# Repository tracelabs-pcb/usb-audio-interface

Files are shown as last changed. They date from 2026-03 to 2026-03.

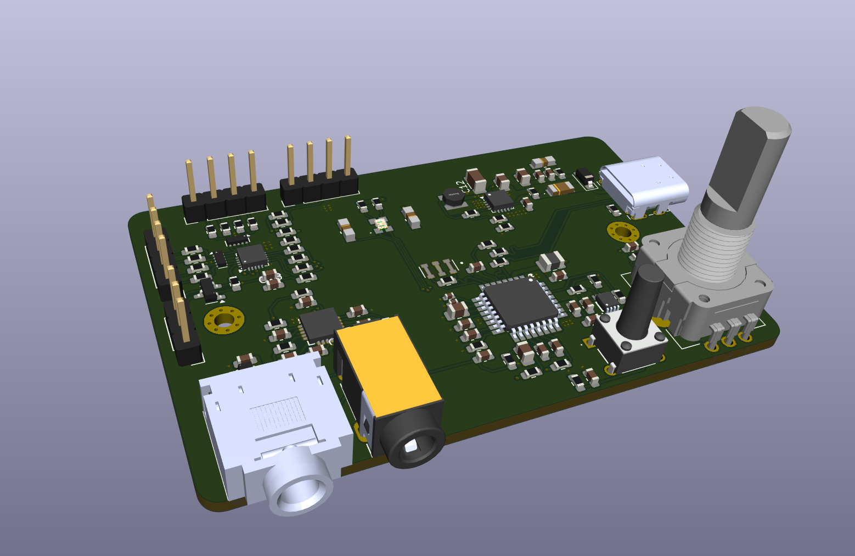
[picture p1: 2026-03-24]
screenshots/pcb_3d.png

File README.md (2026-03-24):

USB-C Audio Interface — Desktop / Streaming / Meetings

**Status: PCB-Design abgeschlossen — unbestückt**  
**Tool:** KiCad | **Layer:** 4-Layer | **Hersteller-ready:** Ja

---

## Projektbeschreibung

Kompaktes USB-C Audio-Interface für Desktop, Streaming und Meetings.
Wird am PC/Mac/Linux als Standard-USB-Audio-Device (UAC2) erkannt,
ohne Treiber. Entwickelt als reproduzierbarer Prototyp mit sauberem
Mixed-Signal-Layout (Analog + Digital).

**Besonderheiten:**
- USB Audio Class 2 (UAC2) — Plug & Play, treiberlos
- Stereo Kopfhörerverstärker mit I²C-Lautstärkeregelung (DirectPath)
- Elektret-Mikrofon-Bias + Hardware-Mute
- Rotary Encoder für Lautstärke + Mute
- Getrennte Digital/Analog-Versorgung (Buck → 3V3D → LDO → 3V3A)
- ESD-Schutz USB + Audio
- Testpunkte für alle kritischen Rails und Signale

---

## Hardware

| Komponente | Beschreibung |
|---|---|
| USB Audio Codec | PCM2912APJTR (ADC + DAC, USB-Enumeration integriert) |
| Kopfhörerverstärker | TPA6130A2RTJR (Stereo, I²C Volume, DirectPath/Capless) |
| Steuer-MCU | ATtiny1616 (Encoder, I²C, Button Handling) |
| Buck Converter | TPS62150A (5V → 3.3V Digital) |
| Analog LDO | TPS7A2033PDBVR (3.3V Digital → 3.3V Analog, Low-Noise) |
| ESD-Schutz | TPD4E05U06DQAR (USB, Audio, GPIO) |
| Stackup | 4-Layer (Signal / GND-Plane / Power / Signal+Pour) |
| Tool | KiCad |

---

## Anschlüsse

- USB-C  — Daten + Versorgung (Bus-Powered)
- TRRS 3.5mm Klinke CTIA (Headset: Mic + L/R + GND)
- Rotary Encoder (Lautstärke + Mute)
- LEDs: Power, Mic-Mute, Clip/Status
- I²C Header (OLED / Erweiterung)
- GPIO Header
- UPDI Header (ATtiny Programmierung)

---

## Architektur

**Versorgung:**
USB 5V → Buck (TPS62150A) → 3V3 Digital → LDO (TPS7A2033) → 3V3 Analog

**Signalführung:**
- USB D+/D− als Differential Pair
- Audio-Pfade kurz, getrennt von Digital
- Keine GND-Splits — gemeinsame GND-Plane (L2 durchgehend)

**Testpunkte:** 5V, 3V3D, 3V3A, GND, USB D+/D−, Audio-Nodes

---

## Ausschlüsse

Kein Serienprodukt — kein CE/EMV, keine Normenfreigabe,
keine sicherheitskritischen Funktionen.

---

## Dateien in diesem Repository

- `/kicad/` — KiCad Projektdateien
- `/screenshots/` — PCB- und Schematic-Ansichten

---

> Entwickelt von [Shawn Schneider](https://tracelabs-pcb.de)  
> — PCB-Design & Lötservice, Wolfsburg

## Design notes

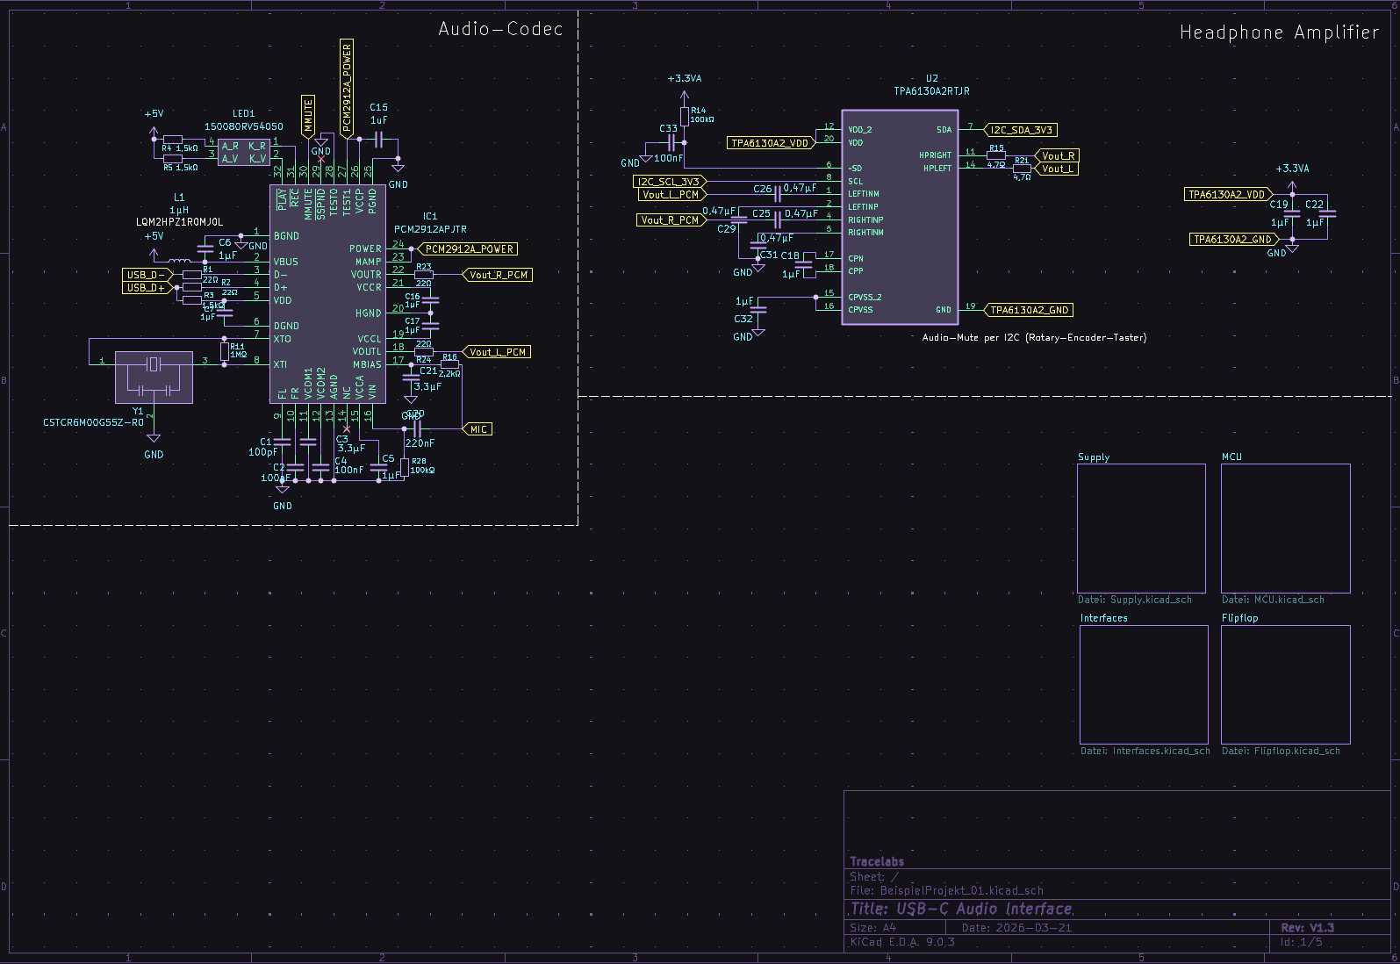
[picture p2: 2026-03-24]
screenshots/schematic_main.png

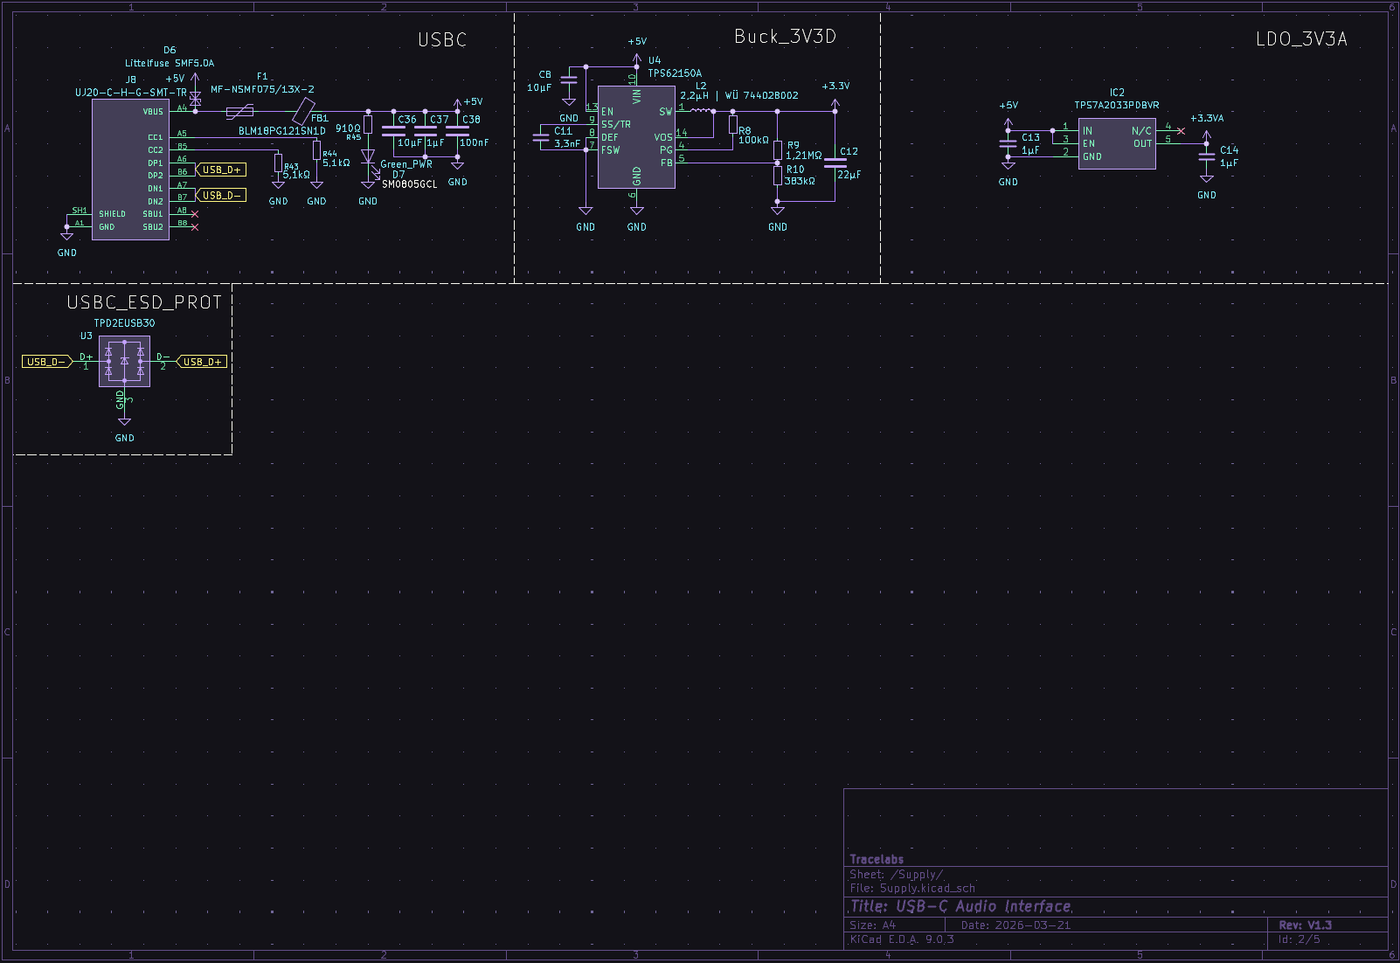
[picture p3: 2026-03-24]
screenshots/schematic_supply.png

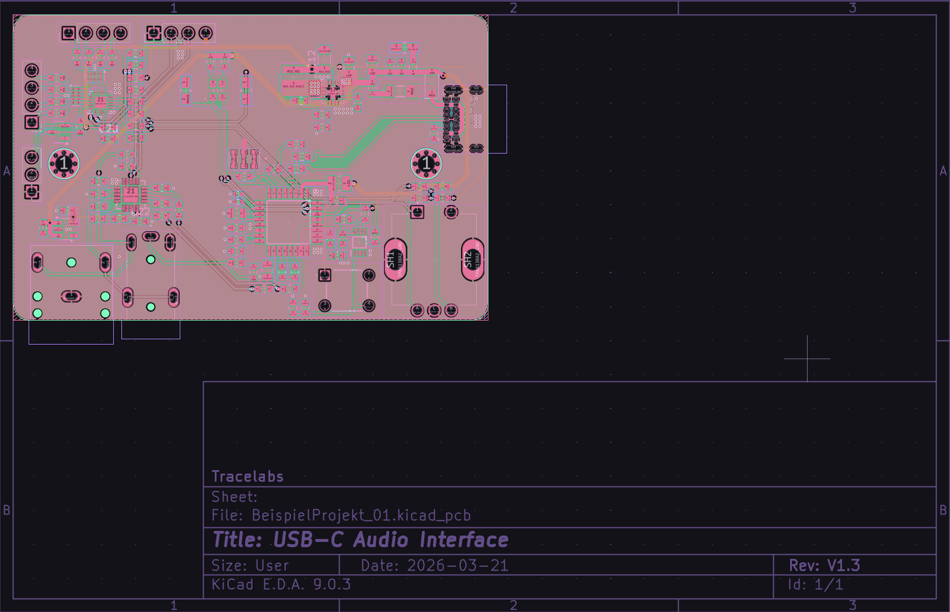
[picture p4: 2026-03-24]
screenshots/pcb_all_layers.png

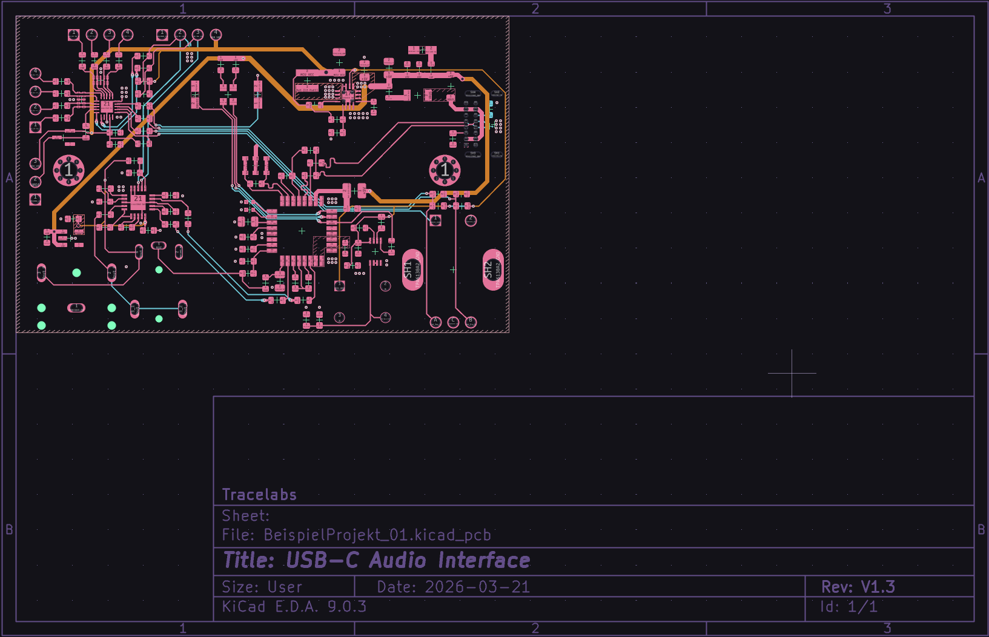
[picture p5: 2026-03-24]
screenshots/pcb_routing.png

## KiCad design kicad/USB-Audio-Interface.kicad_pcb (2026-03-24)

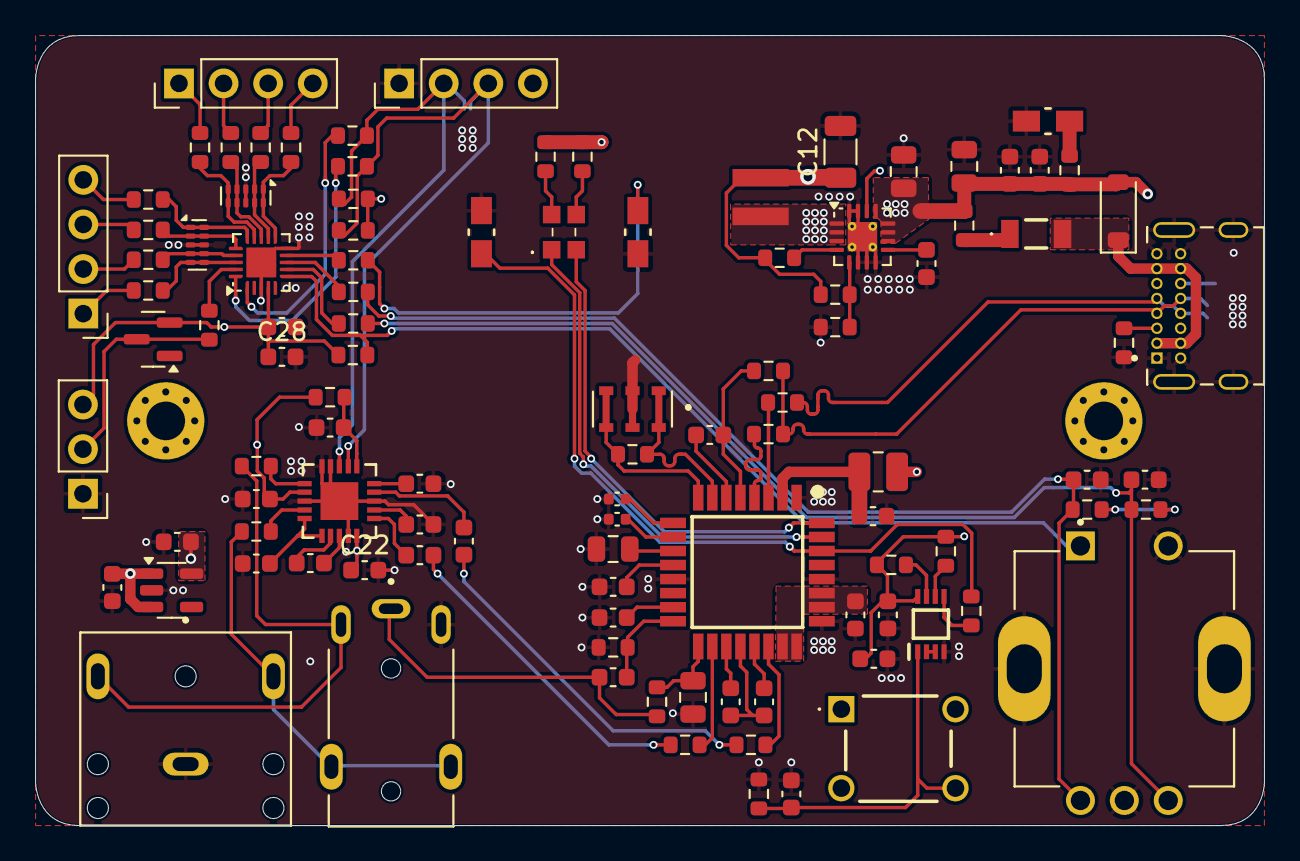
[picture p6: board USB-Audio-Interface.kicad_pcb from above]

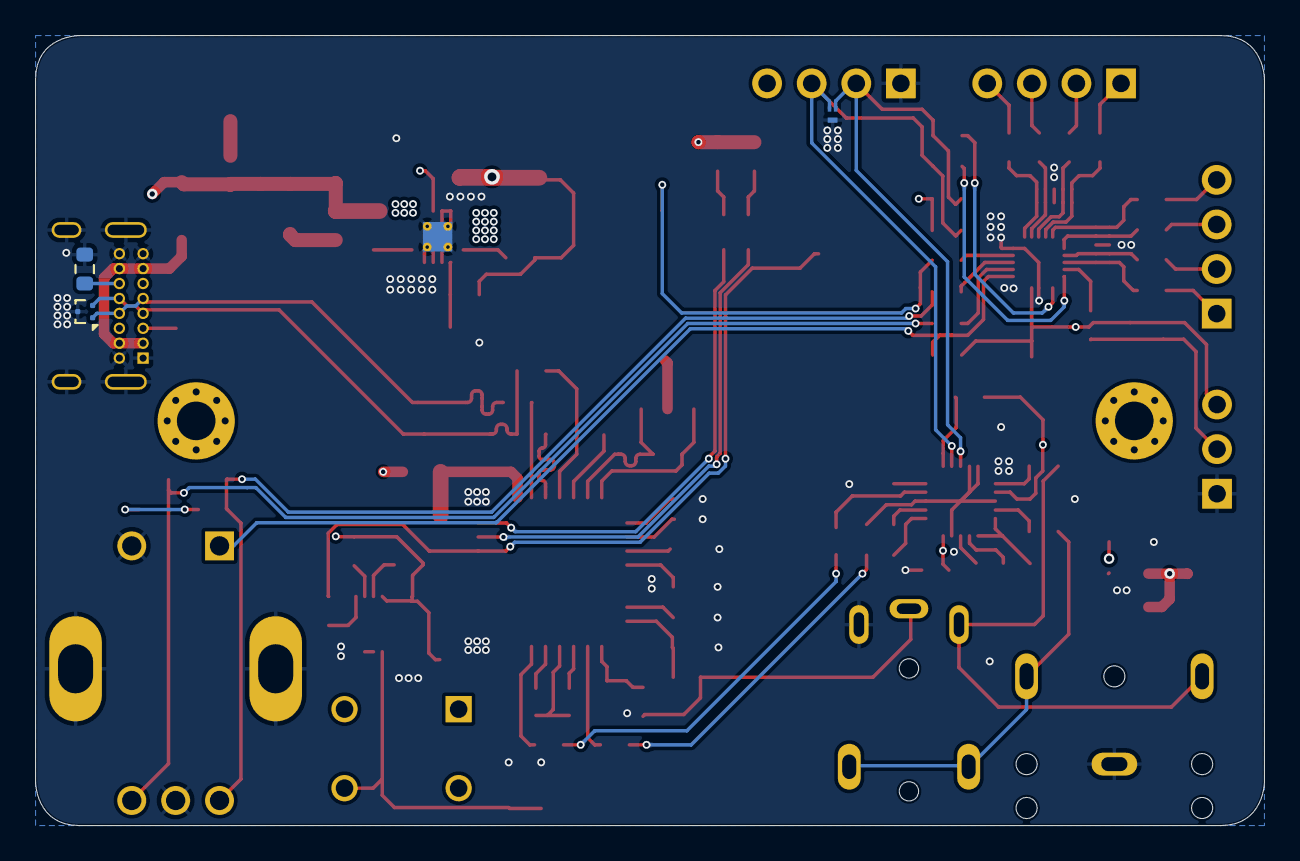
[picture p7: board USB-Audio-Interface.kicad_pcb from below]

Board: 4 copper layers, 70.0 x 45.0 mm, 108 parts (3 on the bottom side), 89 nets.

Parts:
C1, C2: 100pF; C_0402_1005Metric
C3, C21: 3,3µF; C_0805_2012Metric
C4, C22#2, C23, C24, C27, C33, C38: 100nF; C_0603_1608Metric
C5, C6, C7, C13, C14, C16, C17, C18, C19, C22, C28, C32, C37: 1µF; C_0603_1608Metric
C8, C36: 10µF; C_0805_2012Metric
C11: 3,3nF; C_0603_1608Metric
C12: 22µF; C_1206_3216Metric
C15: 1uF; C_0603_1608Metric
C20: 220nF; C_0603_1608Metric
C25, C26, C29, C31: 0,47µF; C_0603_1608Metric
C34, C35: 10nF; C_0603_1608Metric
CR1: PESD5V0X2UAMB; DFN10006B-3_SOT883B_NEX
D1, D4: RED; SM0805HCL_BIV
D3: BAT54A; SOT-23
D6: Littelfuse SMF5.0A; D_SOD-123
D7: Green_PWR; SM0805HCL_BIV
F1: MF-NSMF075/13X-2; MFNSMF07513X2
FB1: BLM18PG121SN1D; R_0603_1608Metric
IC1: PCM2912APJTR; QFP80P900X900X120-32N
IC2: TPS7A2033PDBVR; SOT-23-5
IC3: 74LVC1G74DC,125; SOP50P310X100-8N
J1: FC68125; CLIFF_FC68125
J3: SJ1-3523N; CUI_SJ1-3523N
J4: Conn_01x03_Pin; PinHeader_1x03_P2.54mm_Vertical
J5, J6, J7: Conn_01x04_Pin; PinHeader_1x04_P2.54mm_Vertical
J8: UJ20-C-H-G-SMT-TR; CUI_UJ20-C-H-G-SMT-TR
L1: 1µH; L_1008_2520Metric
L2: 2,2µH | WÜ 744028002; WE-TPC_282892
LED1: 150080RV54050
R1, R2, R23, R24: 22Ω; R_0603_1608Metric
R3, R4, R5: 1,5kΩ; R_0603_1608Metric
R8, R14, R19, R28: 100kΩ; R_0603_1608Metric
R9: 1,21MΩ; R_0603_1608Metric
R10: 383kΩ; R_0603_1608Metric
R11: 1MΩ; R_0603_1608Metric
R12, R13: 33Ω; R_0603_1608Metric
R15, R21: 4,7Ω; R_0603_1608Metric
R16: 2,2kΩ; R_0603_1608Metric
R17, R18, R29, R30, R33: 10kΩ; R_0603_1608Metric
R20, R22: 430Ω; R_0603_1608Metric
R25, R26, R27: 4,7kΩ; R_0603_1608Metric
R31, R32, R35, R36, R37, R38, R39, R40, R41, R42: 100Ω; R_0603_1608Metric
R43, R44: 5,1kΩ; R_0603_1608Metric
R45: 910Ω; R_0603_1608Metric
S2: PEC11R-4220F-S0024; XDCR_PEC11R-4220F-S0024
S3: TS02-66-120-BK-160-LCR-D; TS0266120BK160LCRD
U1: ATtiny1616-M; VQFN-20-1EP_3x3mm_P0.4mm_EP1.7x1.7mm
U2: TPA6130A2RTJR; QFN50P400X400X80-21N
U3: TPD2EUSB30; Texas_DRT-3
U4: TPS62150A; VQFN-16-1EP_3x3mm_P0.5mm_EP1.68x1.68mm_ThermalVias
U7, U8: TPD4E05U06DQA; USON-10_2.5x1.0mm_P0.5mm
Y1: CSTCR6M00G55Z-R0; OSC_CSTCR6M00G55Z-R0

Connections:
+5V: C8.1, C13.1, C36.1, C37.1, C38.1, D6.2 (A2), FB1.2, IC2.1 (IN), IC2.3 (EN), L1.1, R4.1, R5.1, R45.2, U4.10 (VIN), U4.11 (VIN), U4.12 (VIN), U4.13 (EN)
AUDIO_MUTE: R33.1, S2.1, U1.6 (PA5)
I2C_SCL_3V3: CR1.1, J5.2, R13.2, R27.1, U2.8 (SCL)
I2C_SDA_3V3: CR1.2, J5.3, R12.2, R26.1, U2.7 (SDA)
MCU_VCC: C12.1, C22#2.1, C23.1, C27.1, C28.1, D3.2, IC3.8 (VCC), J4.3, J5.4, L2.2, R8.1, R9.1, R17.1, R18.1, R26.2, R27.2, R29.2, R30.2, R33.2, S3.1, U1.4 (VCC), U4.14 (VOS)
MIC: C20.2, J1.1, R16.2
MMUTE: D1.2 (A), IC1.30 (MMUTE), R20.2
unnamed: D4.2 (A), R22.2
unnamed: D7.2 (A), R45.1
unnamed: F1.1, FB1.1
unnamed: IC1.4 (D+), R2.2
unnamed: IC1.3 (D-), R1.2
unnamed: C7.1, IC1.6 (DGND)
unnamed: C1.1, IC1.9 (FL)
unnamed: C2.1, IC1.10 (FR)
unnamed: C16.2, C17.1, IC1.20 (HGND)
unnamed: C21.1, IC1.17 (MBIAS), R16.1
unnamed: C6.1, IC1.2 (VBUS), L1.2
unnamed: C5.1, IC1.15 (VCCA)
unnamed: C17.2, IC1.19 (VCCL)
unnamed: C16.1, IC1.21 (VCCR)
unnamed: C3.1, IC1.11 (VCOM1)
unnamed: C4.1, IC1.12 (VCOM2)
unnamed: C7.2, IC1.5 (VDD), R3.2
unnamed: C20.1, IC1.16 (VIN), R28.2
unnamed: IC1.18 (VOUTL), R24.2
unnamed: IC1.22 (VOUTR), R23.2
unnamed: IC1.8 (XTI), R11.1, Y1.3
unnamed: IC1.7 (XTO), R11.2, Y1.1
unnamed: IC1.32 (~PLAY), LED1.2 (K_V)
unnamed: IC1.31 (~REC), LED1.1 (K_R)
unnamed: C24.1, IC3.1 (CP), R19.1, S3.4
unnamed: IC3.2 (D), IC3.3 (~Q)
unnamed: IC3.5 (Q), R20.1
unnamed: IC3.6 (~RD), R18.2
unnamed: IC3.7 (~SD), R17.2
unnamed: J6.1, R35.1
unnamed: J6.2, R36.1
unnamed: J6.3, R37.1
unnamed: J6.4, R38.1
unnamed: J7.1, R39.1
unnamed: J7.2, R40.1
unnamed: J7.3, R41.1
unnamed: J7.4, R42.1
unnamed: J8.A5 (CC1), R44.1
unnamed: J8.B5 (CC2), R43.1
unnamed: L2.1, U4.1 (SW), U4.2 (SW), U4.3 (SW)
unnamed: LED1.4 (A_R), R4.2
unnamed: LED1.3 (A_V), R5.2
unnamed: R12.1, U1.20 (PA1)
unnamed: R13.1, U1.1 (PA2)
unnamed: R31.1, U1.7 (PA6)
unnamed: R32.1, U1.8 (PA7)
unnamed: R22.1, U1.9 (PB5)
unnamed: R25.1, U1.19 (~RESET/PA0)
unnamed: C18.1, U2.17 (CPN)
unnamed: C18.2, U2.18 (CPP)
unnamed: C32.2, U2.15 (CPVSS_2), U2.16 (CPVSS)
unnamed: R21.1, U2.14 (HPLEFT)
unnamed: R15.2, U2.11 (HPRIGHT)
unnamed: C26.2, U2.1 (LEFTINM)
unnamed: C29.2, U2.2 (LEFTINP)
unnamed: C31.2, U2.5 (RIGHTINM)
unnamed: C25.2, U2.4 (RIGHTINP)
unnamed: C33.1, R14.1, U2.6 (~SD)
unnamed: R9.2, R10.1, U4.5 (FB)
unnamed: R8.2, U4.4 (PG)
unnamed: C11.1, U4.9 (SS/TR)
PB0: R35.2, U1.14 (PB0), U8.5 (D2-), U8.6 (NC)
PB1: R36.2, U1.13 (PB1), U8.4 (D2+), U8.7 (NC)
PB2: R37.2, U1.12 (PB2), U8.2 (D1-), U8.9 (NC)
PB3: R38.2, U1.11 (PB3), U8.1 (D1+), U8.10 (NC)
PC0: R42.2, U1.15 (PC0), U7.1 (D1+), U7.10 (NC)
PC1: R41.2, U1.16 (PC1), U7.2 (D1-), U7.9 (NC)
PC2: R40.2, U1.17 (PC2), U7.4 (D2+), U7.7 (NC)
PC3: R39.2, U1.18 (PC3), U7.5 (D2-), U7.6 (NC)
PCM2912A_POWER: C15.2, IC1.23 (MAMP), IC1.24 (POWER), IC1.26 (VCCP), IC1.27 (TEST1)
Rot_Enc_A: C34.1, R29.1, R32.2, S2.A
Rot_Enc_B: C35.1, R30.1, R31.2, S2.B
TPA6130A2_GND: C1.2, C2.2, C3.2, C4.2, C5.2, C6.2, C8.2, C11.2, C12.2, C13.2, C14.2, C15.1, C19.2, C21.2, C22.2, C22#2.2, C23.2, C24.2, C27.2, C28.2, C29.1, C31.1, C32.1, C33.2, C34.2, C35.2, C36.2, C37.2, C38.2, CR1.3, D1.1 (K), D4.1 (K), D7.1 (K), IC1.1 (BGND), IC1.13 (AGND), IC1.25 (PGND), IC1.28 (TEST0), IC2.2 (GND), IC3.4 (GND), J1.2, J3.1, J4.1, J5.1, J8.A1 (GND), J8.A12 (GND), J8.B1 (GND), J8.B12 (GND), J8.SH1 (SHIELD), J8.SH2 (SHIELD), J8.SH3 (SHIELD), J8.SH4 (SHIELD), R10.2, R19.2, R28.1, R43.2, R44.2, S2.2, S2.C (COM), S2.SH1 (SHIELD), S2.SH2 (SHIELD), U1.3 (GND), U1.10 (PB4), U1.21 (GND), U2.3 (GND_2), U2.9 (GND_3), U2.10 (GND_4), U2.13 (GND_5), U2.19 (GND), U2.21 (EP), U3.3 (GND), U4.6 (GND), U4.7 (FSW), U4.8 (DEF), U4.15 (GND), U4.16 (GND), U4.17 (GND), U7.3 (GND), U7.8 (GND), U8.3 (GND), U8.8 (GND), Y1.2
TPA6130A2_VDD: C14.1, C19.1, C22.1, IC2.5 (OUT), R14.2, U2.12 (VDD_2), U2.20 (VDD)
UPDI: D3.3, J4.2, R25.2
USB_D+: J8.A6 (DP1), J8.B6 (DP2), R2.1, R3.1, U3.2 (D-)
USB_D-: J8.A7 (DN1), J8.B7 (DN2), R1.1, U3.1 (D+)
VBUS: D6.1 (A1), F1.2, J8.A4 (VBUS), J8.A9 (VBUS), J8.B4 (VBUS), J8.B9 (VBUS)
Vout_L: J1.3_1, J1.3_2, J3.2, R21.2
Vout_L_PCM: C26.1, R24.1
Vout_R: J1.6, J3.3, R15.1
Vout_R_PCM: C25.1, R23.1

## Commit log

2026-03-24 Add kicad folder
2026-03-24 Add KiCad project files
    [Flipflop.kicad_sch, Interfaces.kicad_sch, MCU.kicad_sch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]
